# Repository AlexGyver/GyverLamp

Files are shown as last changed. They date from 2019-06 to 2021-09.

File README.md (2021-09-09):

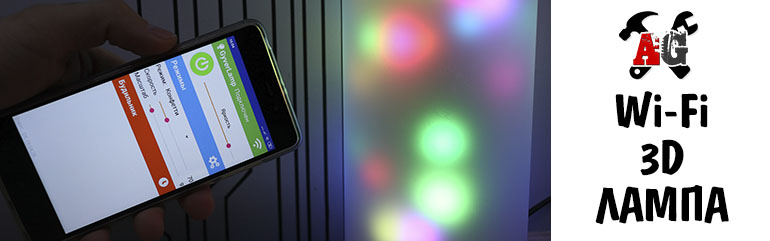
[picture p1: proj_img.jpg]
PROJECT_PHOTO

# Крутая WiFi лампа на esp8266 своими руками
* [Описание проекта](#chapter-0)
* [Папки проекта](#chapter-1)
* [Схемы подключения](#chapter-2)
* [Материалы и компоненты](#chapter-3)
* [Как скачать и прошить](#chapter-4)
* [FAQ](#chapter-5)
* [Полезная информация](#chapter-6)
AlexGyver YouTube (https://www.youtube.com/channel/UCgtAOyEQdAyjvm9ATCi_Aig?sub_confirmation=1)

## Описание проекта
Представляю вашему вниманию светильник на адресных светодиодах с кучей эффектов, управлением по Wi-Fi и функцией будильник-рассвет!
### Железо
- Проект собран на базе микроконтроллера ESP8266 в лице платы NodeMCU или Wemos D1 mini (неважно, какую из этих плат использовать!).
- Вместо адресной ленты используется гибкая адресная матрица 16×16, что выходит дешевле ленты (матрица 16×16 стоит 1500р, она состоит из 256 диодов с плотностью 100 штук на метр. Лента такой же плотности стоит 1000р за метр (за 100 светодиодов). Для склейки матрицы размером 16×16 понадобится 2.5 метра ленты, то есть 2500р. А готовая матрица стоит на 1000р дешевле!).
- Система управляется со смартфона по Wi-Fi (приложение GyverLamp для Android), а также “оффлайн” с кнопки на корпусе (сенсорная кнопка на TTP223).

### Фишки
- 14 крутых эффектов
- Настройка скорости, яркости и “масштаба” для каждого эффекта
- Настройка эффектов со смартфона
- Работа системы как в локальной сети, так и в режиме “точки доступа”
- Встроенный Wi-Fi менеджер для удобной настройки сети
- Система получает точное время из Интернета
- Управление кнопкой: смена режима, настройка яркости, вкл/выкл
- Режим будильник-рассвет: менеджер будильников на неделю в приложении

### Корпус
- Корпус выглядит очень презентабельно, несмотря на простоту и доступность материалов
- Рассеиватель – матовый плафон из Леруа Мерлен
- Остальные элементы корпуса – канализационные трубы, в лучших традициях жанра!
- Страница проекта на сайте: https://alexgyver.ru/GyverLamp/

## Папки
**ВНИМАНИЕ! Если это твой первый опыт работы с Arduino, читай [инструкцию](#chapter-4)**
- **libraries** - библиотеки проекта. Заменить имеющиеся версии
- **firmware** - прошивки для Arduino
- **schemes** - схемы подключения компонентов

## Схемы
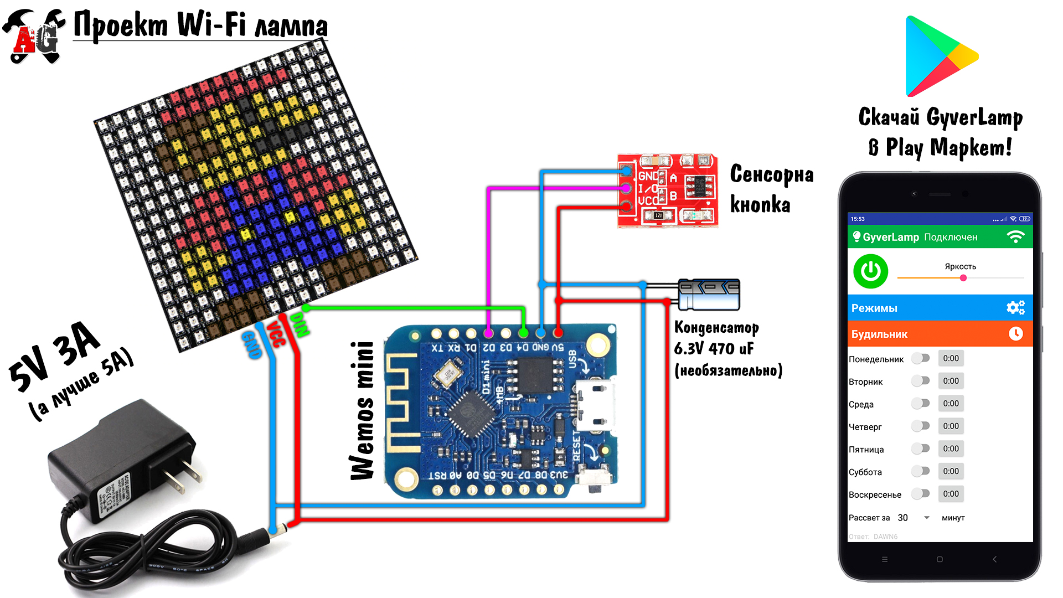
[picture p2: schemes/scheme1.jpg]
SCHEME

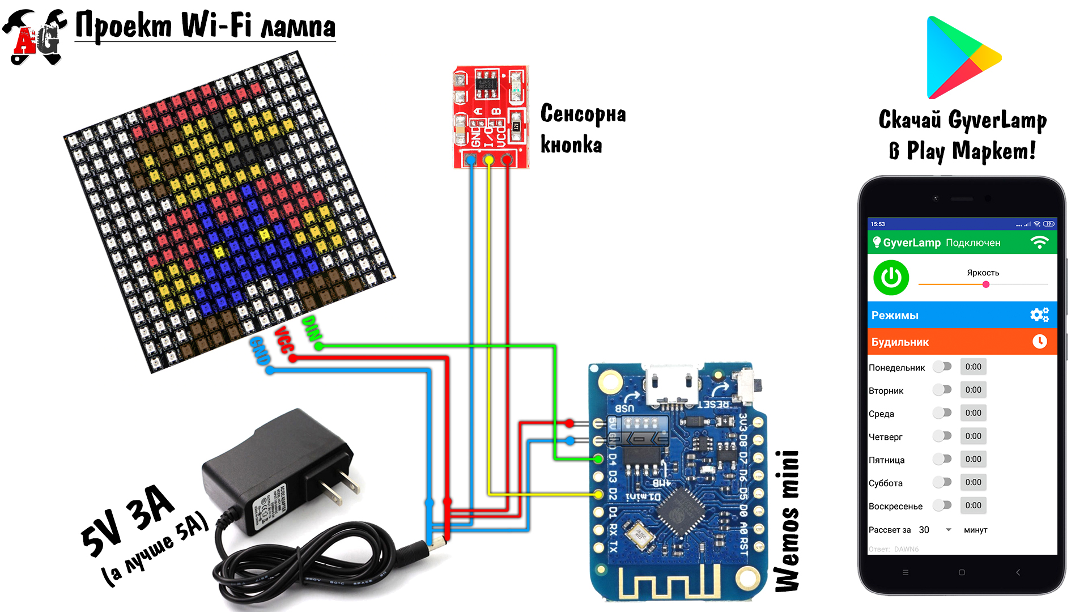
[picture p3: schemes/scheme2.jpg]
SCHEME


## Материалы и компоненты
### Ссылки оставлены на магазины, с которых я закупаюсь уже не один год
Wemos D1 mini – искать
* https://ali.ski/1_oipS
* https://ali.ski/EO_w2z
* https://ali.ski/QKymk
* https://ali.ski/Pzxf_G
NodeMCU – искать
* https://ali.ski/F2FeBB
* https://ali.ski/j76J_I
Матрица 16×16 – искать
* https://ali.ski/lkB8g
* https://ali.ski/CaiZgG
* https://ali.ski/9hcHX
* https://ali.ski/4zxlz
* Матрица 8×8 купить в РФ
Адресная лента (для DIY матрицы)
* https://ali.ski/oEXGJI
* https://ali.ski/VuxYof
* Купить в РФ, 60 свет/метр, 30 свет/метр
* Black PCB / White PCB – цвет подложки ленты, чёрная / белая. В видео была чёрная
* 1m/5m – длина ленты в метрах (чтобы заказать 2 метра, берите два заказа 1m, очевидно)
* 30/60/74/96/100/144 – количество светодиодов на 1 метр ленты. В видео использовалась лента 60 диодов на метр
* IP30 лента без влагозащиты (как на видео)
* IP65 лента покрыта силиконом
* IP67 лента полностью в силиконовом коробе
* Постфикс ECO – лента чуть более низкого качества, меньше меди, на длинной ленте будет сильно проседать яркость
Сенсорная кнопка – искать
* https://ali.ski/zzTzeO
* https://ali.ski/DbCM-A
* БП 5V искать (минимум 3A на каждые 100 LED)
* https://ali.ski/8dQhKV
* https://ali.ski/-ppLAQ
* Мощные https://ali.ski/UwKWR
* Мощные https://ali.ski/W-3Gs
* БП 60W (купить в РФ)
* БП 100W (купить в РФ)
Проводочки – искать
* https://ali.ski/Jb-RZJ
Сантех
* Труба D50 длина 250
* Труба D40 короткая
* Заглушка D40

## Вам скорее всего пригодится
* [Всё для пайки (паяльники и примочки)](http://alexgyver.ru/all-for-soldering/)
* [Недорогие инструменты](http://alexgyver.ru/my_instruments/)
* [Все существующие модули и сенсоры Arduino](http://alexgyver.ru/arduino_shop/)
* [Электронные компоненты](http://alexgyver.ru/electronics/)
* [Аккумуляторы и зарядные модули](http://alexgyver.ru/18650/)

## Как скачать и прошить
* [Первые шаги с Arduino](http://alexgyver.ru/arduino-first/) - ультра подробная статья по началу работы с Ардуино, ознакомиться первым делом!
* Скачать архив с проектом
> На главной странице проекта (где ты читаешь этот текст) вверху справа зелёная кнопка **Clone or download**, вот её жми, там будет **Download ZIP**
* Установить библиотеки в  
`C:\Program Files (x86)\Arduino\libraries\` (Windows x64)  
`C:\Program Files\Arduino\libraries\` (Windows x86)
* **Подключить внешнее питание 5 Вольт**
* Подключить плату к компьютеру
* Файл/Настройки, вставить ссылку http://arduino.esp8266.com/stable/package_esp8266com_index.json в в текст-бокс для дополнительных ссылок для менеджера плат
* Открыть Инструменты/Плата/Менеджер плат…, найти esp8266 by ESP8266 Community, установить версию 2.5.0
* Открыть Инструменты, настроить Плату, Порт и другие параметры как на скриншоте
* Загрузить прошивку

## Настройки в коде
    // -------- ВРЕМЯ -------
    GMT 3              // смещение (москва 3)
    NTP_ADDRESS  "europe.pool.ntp.org"    // сервер времени

    // -------- РАССВЕТ -------
    DAWN_BRIGHT 200       // макс. яркость рассвета
    DAWN_TIMEOUT 1        // сколько рассвет светит после времени будильника, минут

    // ---------- МАТРИЦА ---------
    BRIGHTNESS 40         // стандартная маскимальная яркость (0-255)
    CURRENT_LIMIT 2000    // лимит по току в миллиамперах, автоматически управляет яркостью (пожалей свой блок питания!) 0 - выключить лимит

    WIDTH 16              // ширина матрицы
    HEIGHT 16             // высота матрицы

    COLOR_ORDER GRB       // порядок цветов на ленте. Если цвет отображается некорректно - меняйте. Начать можно с RGB

    MATRIX_TYPE 0         // тип матрицы: 0 - зигзаг, 1 - параллельная
    CONNECTION_ANGLE 0    // угол подключения: 0 - левый нижний, 1 - левый верхний, 2 - правый верхний, 3 - правый нижний
    STRIP_DIRECTION 0     // направление ленты из угла: 0 - вправо, 1 - вверх, 2 - влево, 3 - вниз
    // при неправильной настрйоке матрицы вы получите предупреждение "Wrong matrix parameters! Set to default"
    // шпаргалка по настройке матрицы здесь! https://alexgyver.ru/matrix_guide/

    // --------- ESP --------
    ESP_MODE 1
    // 0 - точка доступа (192.168.4.1 или другой)
    // 1 - локальный (192.168.1.232 или другой)

    // -------- Менеджер WiFi ---------
    AC_SSID "AutoConnectAP"
    AC_PASS "12345678"

    // -------------- AP ---------------
    AP_SSID "GyverLamp"
    AP_PASS "12345678"
    AP_PORT 8888

## FAQ
### Основные вопросы
В: Как скачать с этого грёбаного сайта?  
О: На главной странице проекта (где ты читаешь этот текст) вверху справа зелёная кнопка **Clone or download**, вот её жми, там будет **Download ZIP**

В: Скачался какой то файл .zip, куда его теперь?  
О: Это архив. Можно открыть стандартными средствами Windows, но думаю у всех на компьютере установлен WinRAR, архив нужно правой кнопкой и извлечь.

В: Я совсем новичок! Что мне делать с Ардуиной, где взять все программы?  
О: Читай и смотри видос http://alexgyver.ru/arduino-first/

В: Вылетает ошибка загрузки / компиляции!
О: Читай тут: https://alexgyver.ru/arduino-first/#step-5

В: Сколько стоит?  
О: Ничего не продаю.

### Вопросы по этому проекту

## Полезная информация
* [Мой сайт](http://alexgyver.ru/)
* [Основной YouTube канал](https://www.youtube.com/channel/UCgtAOyEQdAyjvm9ATCi_Aig?sub_confirmation=1)
* [YouTube канал про Arduino](https://www.youtube.com/channel/UC4axiS76D784-ofoTdo5zOA?sub_confirmation=1)
* [Мои видеоуроки по пайке](https://www.youtube.com/playlist?list=PLOT_HeyBraBuMIwfSYu7kCKXxQGsUKcqR)
* [Мои видеоуроки по Arduino](http://alexgyver.ru/arduino_lessons/)

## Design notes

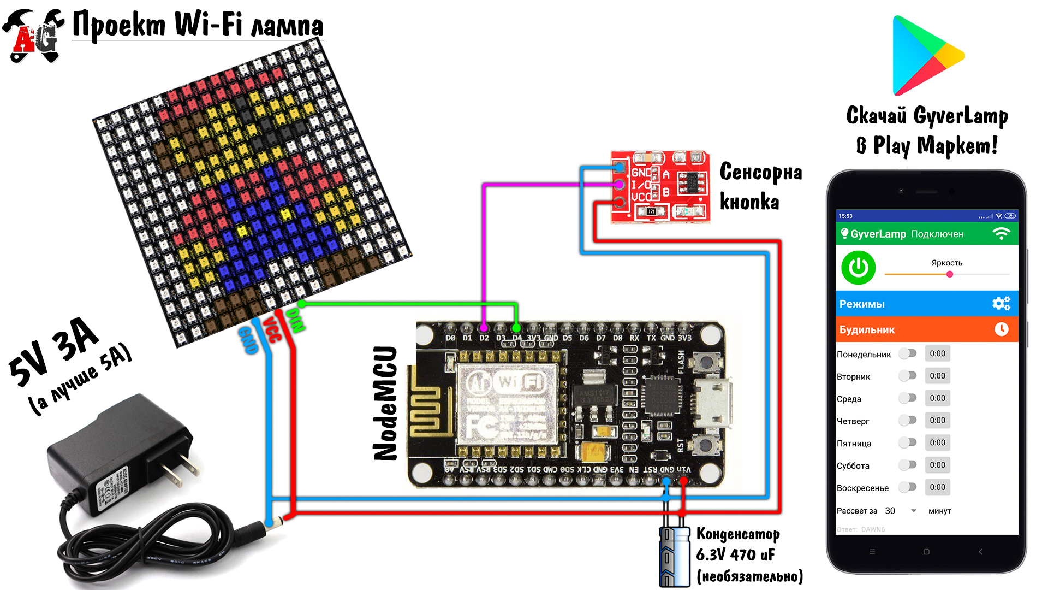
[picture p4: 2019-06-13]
schemes/scheme0.jpg

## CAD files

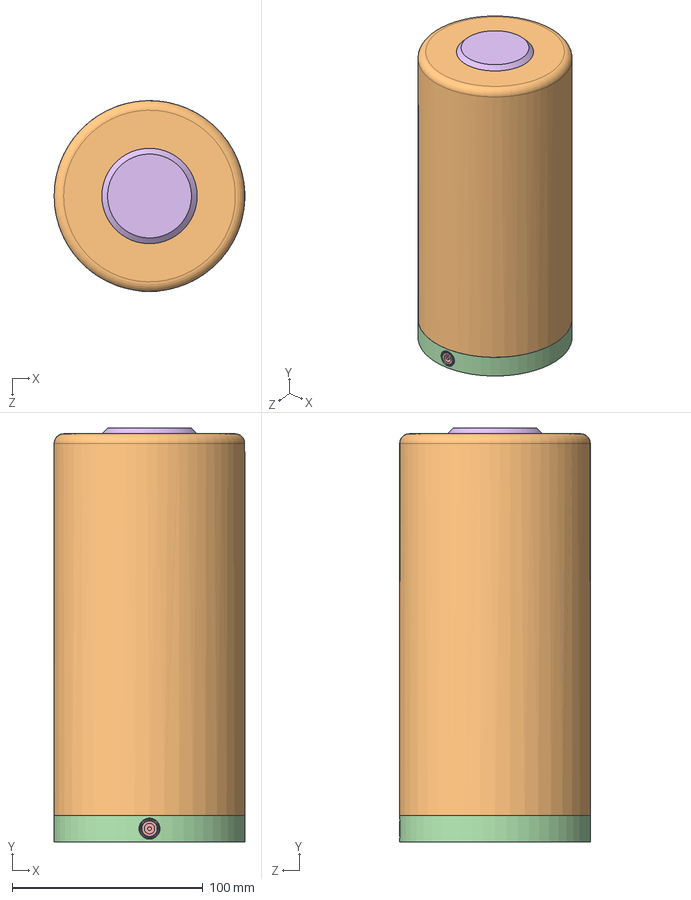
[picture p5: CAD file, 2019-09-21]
3D_print/kokos/исходник/GyverLamp.SLDASM
100.0 x 217.0 x 100.0 mm
Основание
Плафон 20х10
LED_strip 12 x 15
постамент
dc_power_jack_3p5x1p35mm
крышка
Lolin NodeMCU ESP8266 V3
TTP

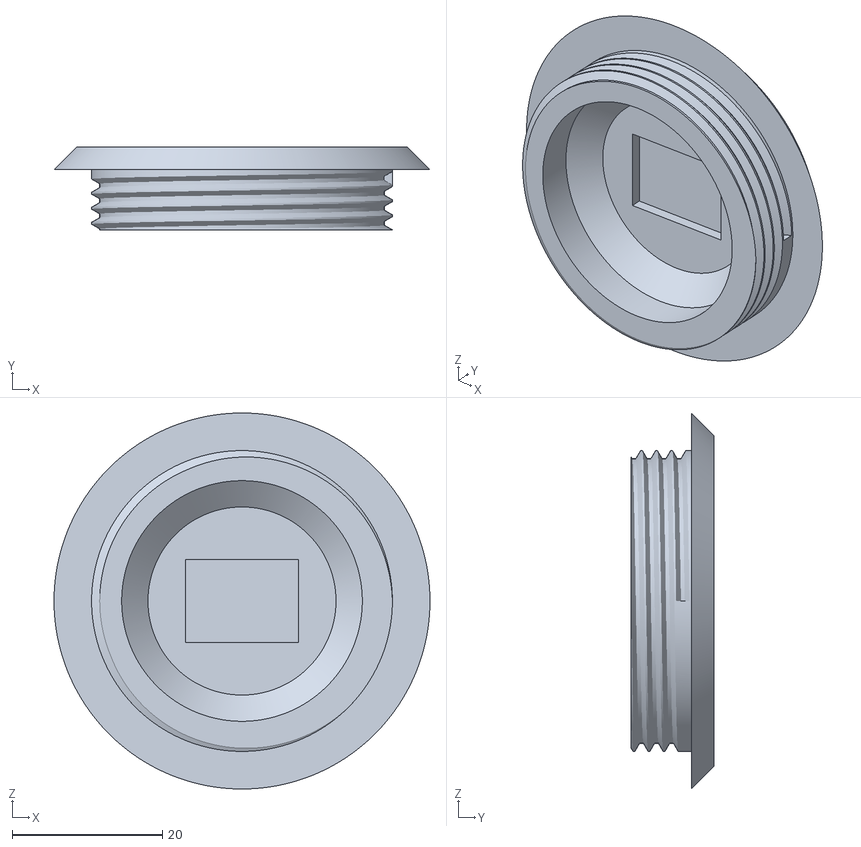
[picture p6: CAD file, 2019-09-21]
3D_print/kokos/stl/крышка.STL
50.0 x 11.0 x 50.0

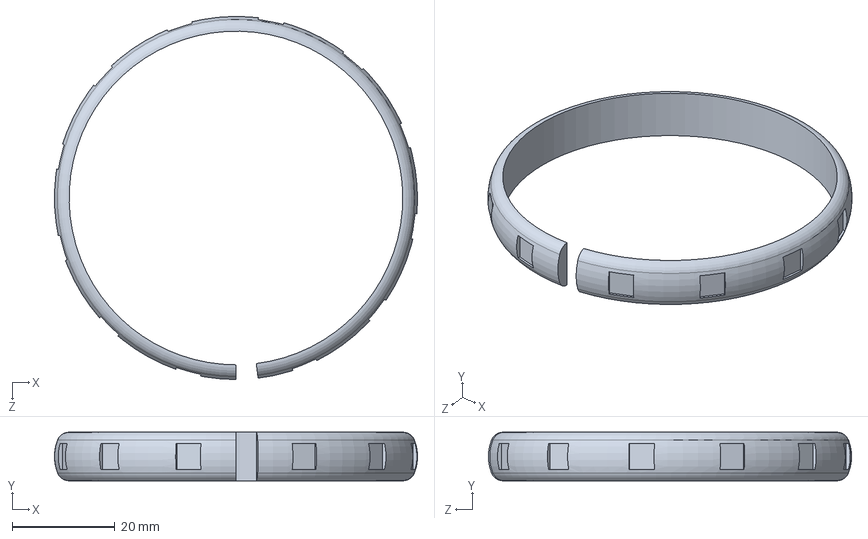
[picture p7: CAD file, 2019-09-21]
3D_print/kokos/исходник/LED_strip 12.SLDPRT
70.7 x 9.50 x 70.7 mm

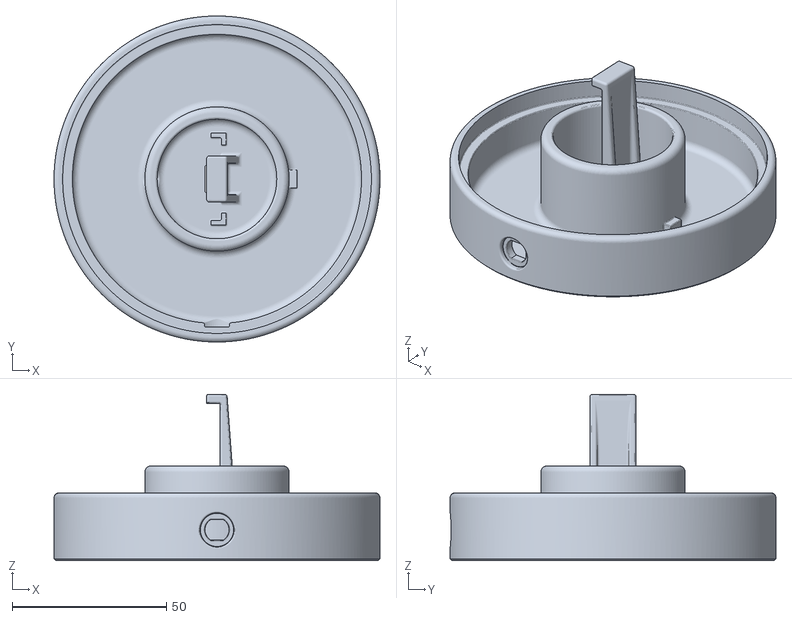
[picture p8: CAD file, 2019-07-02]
3D_print/Евгений/STL/Lamp_Down_DC-output.stl
105.8 x 105.8 x 54.0

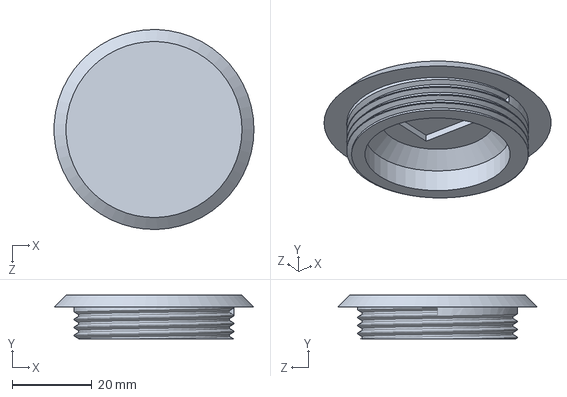
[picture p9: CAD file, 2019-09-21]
3D_print/kokos/исходник/крышка.SLDPRT
50.0 x 11.0 x 50.0 mm

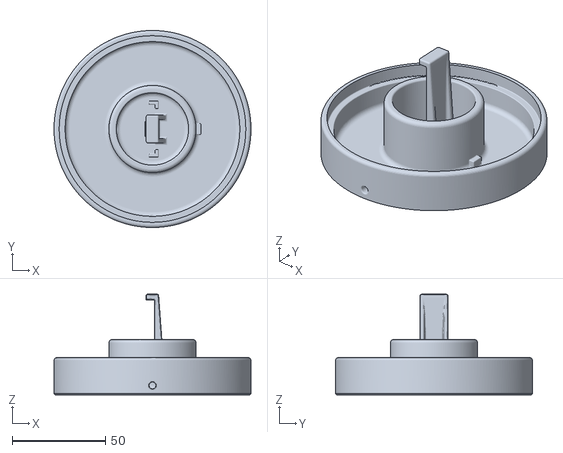
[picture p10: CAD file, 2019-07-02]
3D_print/Евгений/STL/Lamp_Down.stl
105.8 x 105.8 x 54.0

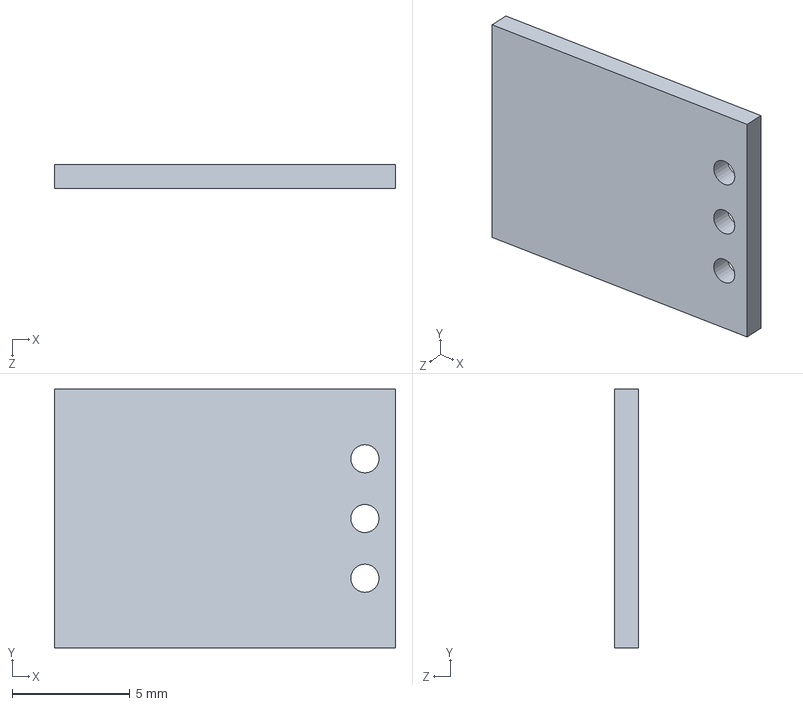
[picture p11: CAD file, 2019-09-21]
3D_print/kokos/исходник/TTP.SLDPRT
14.5 x 11.0 x 1.00 mm

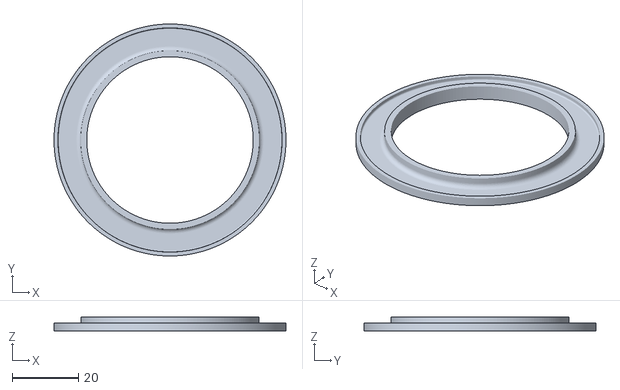
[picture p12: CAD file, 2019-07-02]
3D_print/Евгений/STL/ring_for_paper.stl
70.0 x 70.0 x 4.20

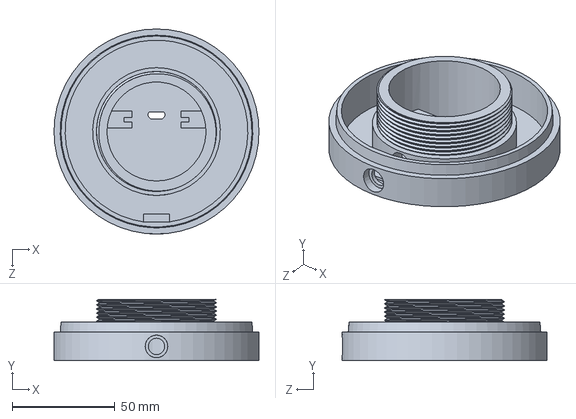
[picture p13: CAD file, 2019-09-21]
3D_print/kokos/исходник/постамент.SLDPRT
100.0 x 30.0 x 100.0 mm

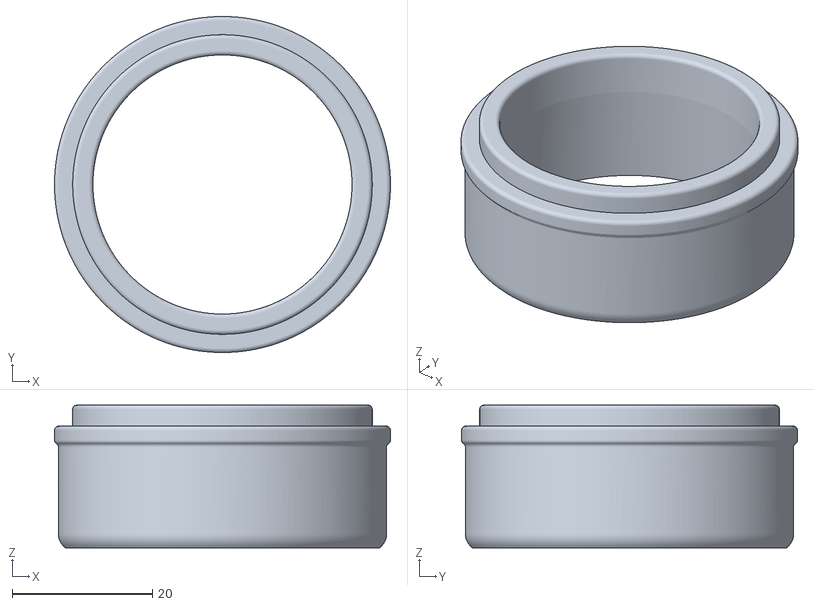
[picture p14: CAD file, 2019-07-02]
3D_print/Евгений/STL/Ring_top.stl
48.0 x 48.0 x 20.4

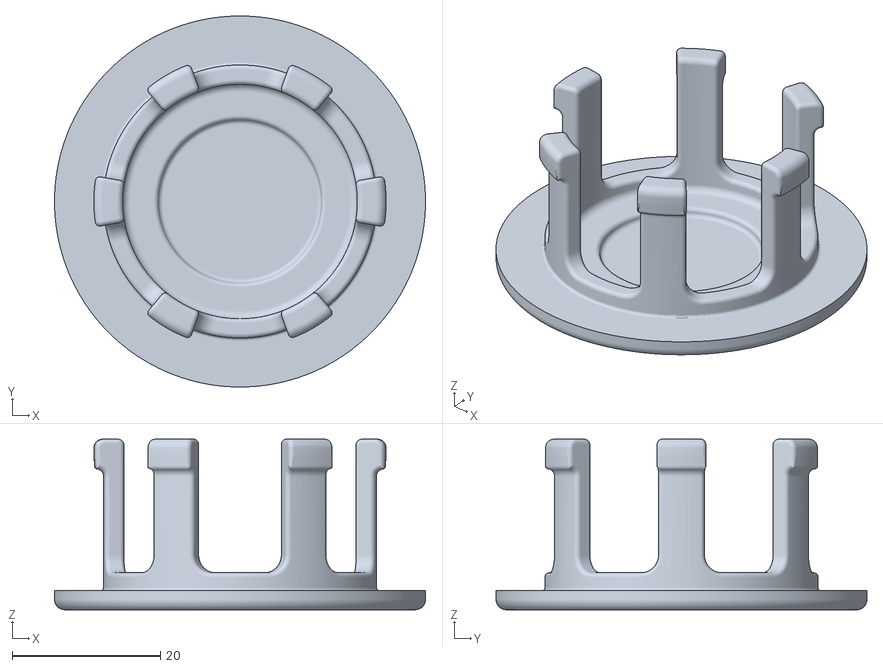
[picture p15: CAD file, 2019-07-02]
3D_print/Евгений/STL/Lamp-Top.stl
50.0 x 50.0 x 23.0

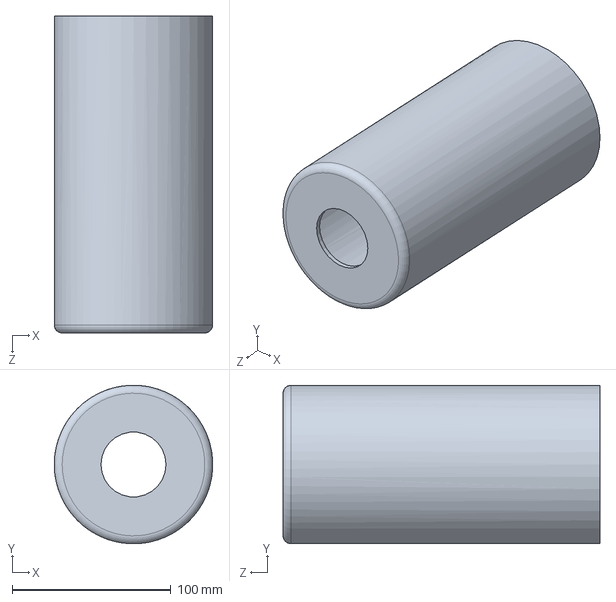
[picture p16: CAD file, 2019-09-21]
3D_print/kokos/исходник/Плафон 20х10.SLDPRT
100.0 x 100.0 x 200.0 mm

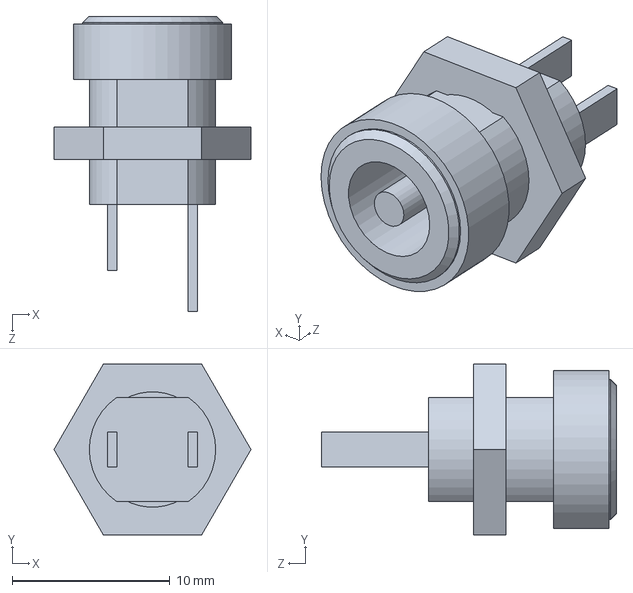
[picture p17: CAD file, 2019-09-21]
3D_print/kokos/исходник/dc_power_jack_3p5x1p35mm.SLDPRT
12.5 x 10.8 x 18.7 mm

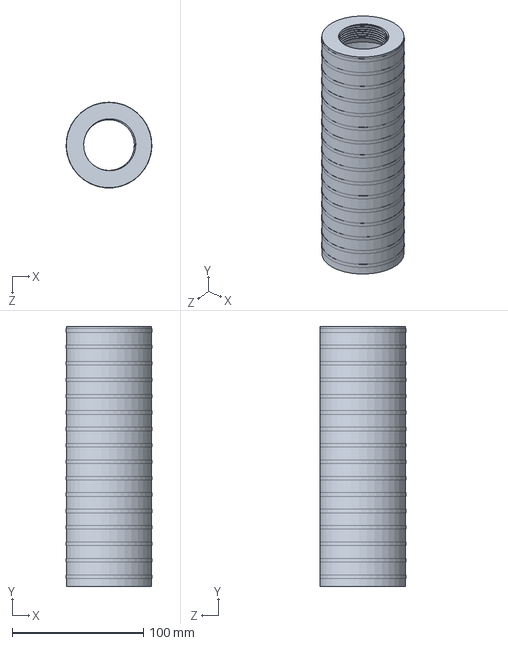
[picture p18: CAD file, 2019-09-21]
3D_print/kokos/исходник/Основание.SLDPRT
65.3 x 198.0 x 65.3 mm

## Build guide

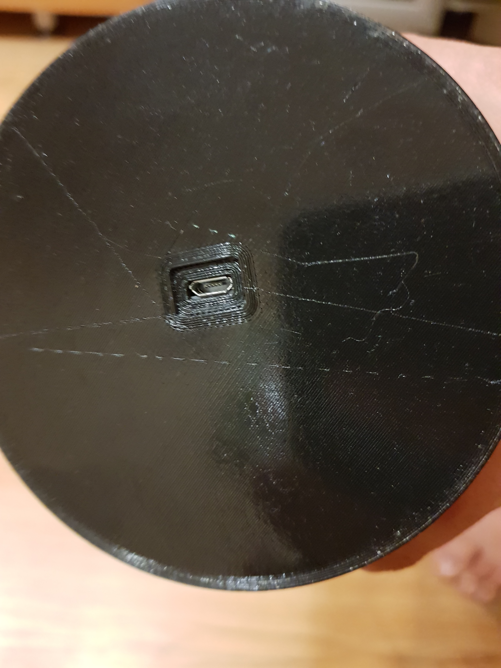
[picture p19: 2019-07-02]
3D_print/Евгений/photo (5).jpg

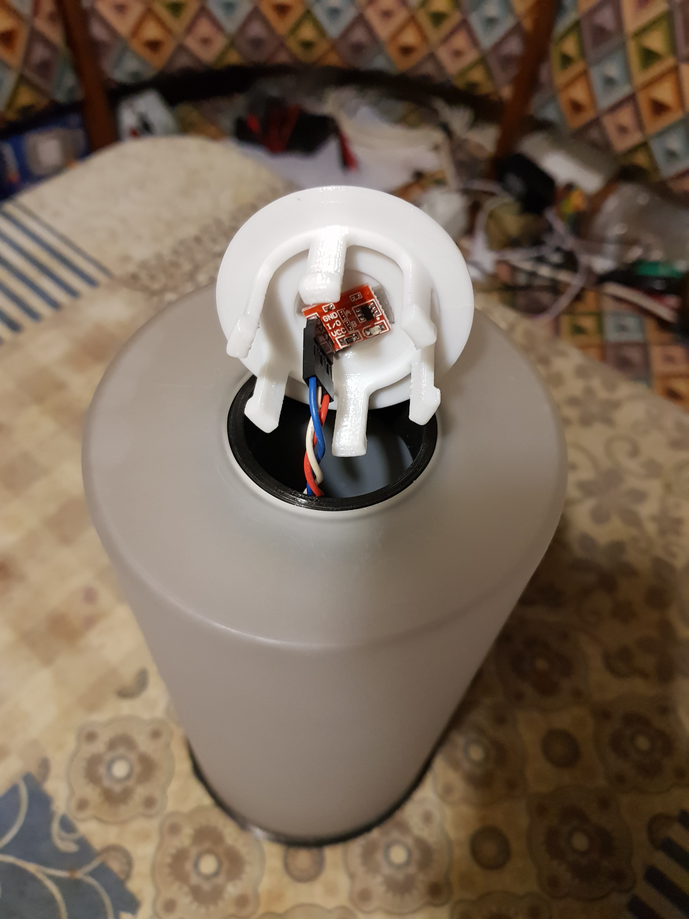
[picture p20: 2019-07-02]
3D_print/Евгений/photo (1).jpg

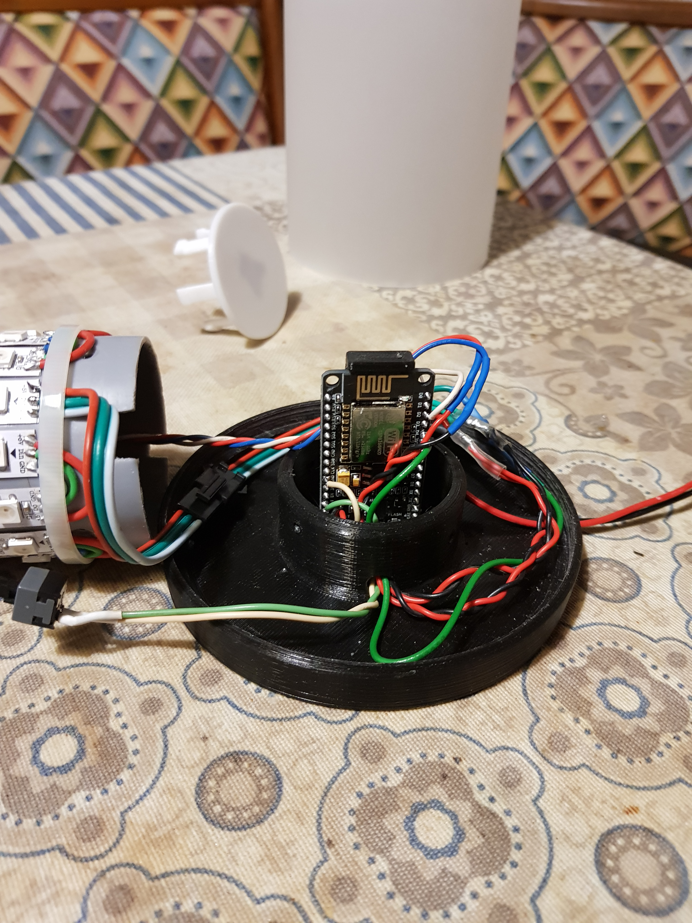
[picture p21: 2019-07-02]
3D_print/Евгений/photo (3).jpg

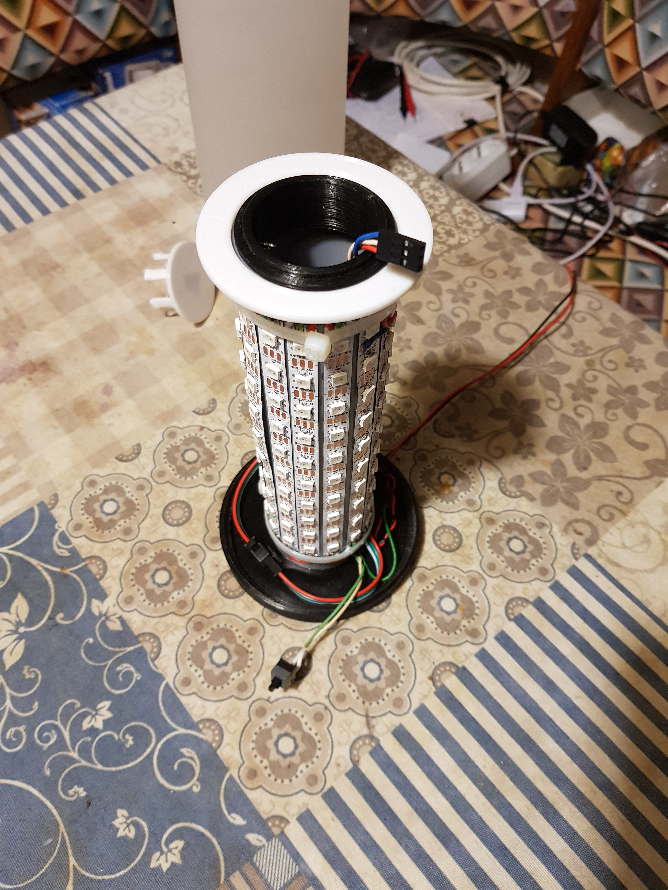
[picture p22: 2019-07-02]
3D_print/Евгений/photo (2).jpg

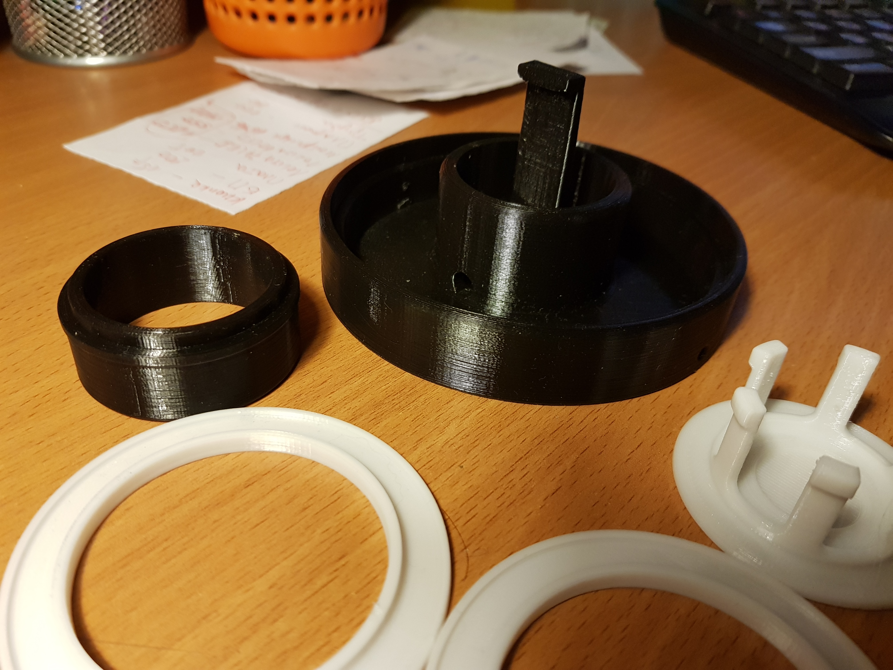
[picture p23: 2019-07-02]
3D_print/Евгений/photo (4).jpg

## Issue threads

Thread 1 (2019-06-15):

Настройки яркости

Yusupoff, 2019-06-15:
При установке яркость на минимальную она постепенно увеличивается обратно до максимума

AlexGyver, 2019-07-01:
проверь как себя чувствует кнопка, "отпускается" ли она

vvip-68, 2019-07-03:
Кнопки вообще нет. Только матрица. И да - если в программе выставить яркость на минимум, она постепенно сама увеличивается до максимума. Правда, я это пробовал в версии 1.2; Не знаю что там с этим в 1.3 или 1.4

AlexGyver, 2019-07-03:
Вот отсутствие кнопки не означает того, что микроконтроллер об этом в курсе. Пин кнопки ловит наводки из воздуха и интерпретирует их в случайное значение17:41, 3 июля 2019 г., "vvip-68" <notifications@github.com>:Кнопки вообще нет. Только матрица. И да - если в программе выставить яркость на минимум, она постепенно сама увеличивается до максимума. Правда, я это пробовал в версии 1.2; Не знаю что там с этим в 1.3 или 1.4

—You are receiving this because you commented.Reply to this email directly, view it on GitHub, or mute the thread.
Яндекс.Почта

Denischet, 2021-10-01:
> Кнопки вообще нет. Только матрица. И да - если в программе выставить яркость на минимум, она постепенно сама увеличивается до максимума. Правда, я это пробовал в версии 1.2; Не знаю что там с этим в 1.3 или 1.4

Не уверен, что увижу ответ, но все же спрошу. Решил ли проблему? Если да  то как? У меня яркость или растет до максимума или падает до минимума. Кнопка есть, но не залипшая, не моргает диодом, во всяком случае. Буду признателен за обратную связь.

vvip-68, 2021-10-01:
*  Этот проект давно устаревший и уже не поддерживается. Все функциональные возможности этого проекта перенесены в GyverPanelWiFi и добавлено много чего еще. Несмотря на то, что проект называется  Panel — по сути это всё та же лампа.
 
*  Описанное происходит скорее всего из за неправильного указания (а следовательно и инициализации) типа кнопки в скетче. Например — подключена сенсорная кнопка, а в скетче кнопка указана как обычная тактовая или наоборот.
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
Не уверен, что увижу ответ, но все же спрошу. Решил ли проблему? Если да то как? У меня яркость или растет до максимума или падает до минимума. Кнопка есть, но не залипшая, не моргает диодом, во всяком случае. Буду признателен за обратную связь.
—
You are receiving this because you commented.
Reply to this email directly,  view it on GitHub , or  unsubscribe .
Triage notifications on the go with GitHub Mobile for  iOS or  Android .   
 
С уважением,
Вадим Пузанов
 

Yusupoff, 2021-10-04:
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

В последних версиях не наблюдается

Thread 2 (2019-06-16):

Отображение времени (часы)

dipcore, 2019-06-16:
Круто бы добавить режим отображения времени. На такая крутой адресной матрице это должно выглядеть хорошо. Можно также сделатьнесколько эфектов отображения/анимации времени.

vvip-68, 2019-06-17:
> Круто бы добавить режим отображения времени. На такой крутой адресной матрице это должно выглядеть хорошо. Можно также сделать несколько эффектов отображения/анимации времени.
Вы конструкцию лампы то видели? При внутреннем радиусе матрицы 50 мм и внешнем радиусе плафона 100 мм цифр будет не различить совсем. А для часов - есть другой проект. Именно в виде плоской матрицы. С эффектом и часами.

dipcore, 2019-06-17:
> Вы конструкцию лампы то видели? При внутреннем диаметре матрицы 50 мм и внешнем диаметре плафона 100 мм цифр будет не различить совсем. А для часов - есть другой проект. Именно в виде плоской матрицы. С эффектом и часами.

Я бы небыл так катигоричен. Конструкцию я видел и отображение времени вполне реализуемо.

vvip-68, 2019-06-17:
Вполне реализуемо. Только зачем? На лампе времени видно не будет, а для проекта плоской матрицы - время есть. Вот время на внешнем индикаторе типа TM1637 - актуально.

dipcore, 2019-06-22:
Будет хорошо видно большие цифры даже через рассеиватель. А со скроллингом было бы вообще класс.

vvip-68, 2019-07-03:
Ну так ставьте GyverMatrixBT или GyverMatrixWiFi в плафон и будет вам счастье.

Pats1337, 2022-06-05:
Тестировал отображение времени на лампе, довольно плохо читаются цифры из-за рассеивающей поверхности плафона из Леруа.

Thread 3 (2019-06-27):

проблема с таймингом без интернета

baxster, 2019-06-27:
При отсутствии интернета вызов метода `timeClient.update();` вешает обработку тика эффекта на секунду. В итоге нет реакции на изменение скорости и т.п.

В библиотечном методе `NTPClient::forceUpdate()` есть кусок кода:
`  // Wait till data is there or timeout...
  byte timeout = 0;
  int cb = 0;
  do {
    delay ( 10 );
    cb = this->_udp->parsePacket();
    if (timeout > 100) return false; // timeout after 1000 ms
    timeout++;
  } while (cb == 0);`

В итоге при каждом выполнении цикла эффекта мы попадаем на таймаут, а так как используется `delay`, а не `millis`, то мы попадаем с эффектами лампы.
Надо как-то это учесть в работе самой лампы и возможно стоит как-то переписать это на `millis()`

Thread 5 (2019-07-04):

добавил некоторве функции и упростил настройку статического IP

Yusupoff, 2019-07-04:
`/*
  Скетч к проекту "Многофункциональный RGB светильник"
  Страница проекта (схемы, описания): https://alexgyver.ru/GyverLamp/
  Исходники на GitHub: https://github.com/AlexGyver/GyverLamp/
  Нравится, как написан код? Поддержи автора! https://alexgyver.ru/support_alex/
  Автор: AlexGyver, AlexGyver Technologies, 2019
  https://AlexGyver.ru/
*/

/*
  Версия 1.2:
  - Добавлена настройка статического IP
  - Добавлен эффект "Цвет"
  - Добавлен эффект "Снег"
  - Добавлен эффект "Матрица"
  - Добавлен эффект "Светлячки"
*/

// Ссылка для менеджера плат:
// http://arduino.esp8266.com/stable/package_esp8266com_index.json

// ============= НАСТРОЙКИ =============
// -------- ВРЕМЯ -------
#define GMT 3              // смещение (москва 3)
#define NTP_ADDRESS  "europe.pool.ntp.org"    // сервер времени

// -------- РАССВЕТ -------
#define DAWN_BRIGHT 200       // макс. яркость рассвета
#define DAWN_TIMEOUT 1        // сколько рассвет светит после времени будильника, минут

// ---------- МАТРИЦА ---------
#define BRIGHTNESS 40         // стандартная маскимальная яркость (0-255)
#define CURRENT_LIMIT 2000    // лимит по току в миллиамперах, автоматически управляет яркостью (пожалей свой блок питания!) 0 - выключить лимит

#define WIDTH 6              // ширина матрицы
#define HEIGHT 9             // высота матрицы

#define COLOR_ORDER GRB       // порядок цветов на ленте. Если цвет отображается некорректно - меняйте. Начать можно с RGB

#define MATRIX_TYPE 1         // тип матрицы: 0 - зигзаг, 1 - параллельная
#define CONNECTION_ANGLE 2    // угол подключения: 0 - левый нижний, 1 - левый верхний, 2 - правый верхний, 3 - правый нижний
#define STRIP_DIRECTION 3     // направление ленты из угла: 0 - вправо, 1 - вверх, 2 - влево, 3 - вниз
// при неправильной настройке матрицы вы получите предупреждение "Wrong matrix parameters! Set to default"
// шпаргалка по настройке матрицы здесь! https://alexgyver.ru/matrix_guide/

// --------- ESP --------
const char HOSTNAME[] = "GyverLamp";
#define ESP_MODE 1
// 0 - точка доступа
// 1 - локальный
byte IP_AP[] = {192, 168, 4, 1};   // статический IP точки доступа (менять только последнюю цифру)

//#define WIFIMGR_PORTAL_TIMEOUT 1
//#define WIFIMGR_SET_MANUAL_IP
#ifdef WIFIMGR_SET_MANUAL_IP
  char static_ip[16] = "10.0.1.56";
  char static_gw[16] = "10.0.1.1";
  char static_sn[16] = "255.255.255.0";
#endif

// ----- AP (точка доступа) -------
#define AP_SSID "GyverLamp"
#define AP_PASS "12345678"
#define AP_PORT 8888

// -------- Менеджер WiFi ---------
#define AC_SSID "AutoAP"
#define AC_PASS "12345678"

// ============= ДЛЯ РАЗРАБОТЧИКОВ =============
#define LED_PIN 2             // пин ленты
#define BTN_PIN 3
#define MODE_AMOUNT 18

#define NUM_LEDS WIDTH * HEIGHT
#define SEGMENTS 1            // диодов в одном "пикселе" (для создания матрицы из кусков ленты)
// ---------------- БИБЛИОТЕКИ -----------------
#define FASTLED_INTERRUPT_RETRY_COUNT 0
#define FASTLED_ALLOW_INTERRUPTS 0
#define FASTLED_ESP8266_RAW_PIN_ORDER
#define NTP_INTERVAL 60 * 1000    // обновление (1 минута)

#include "timerMinim.h"
#include <FastLED.h>
#include <ESP8266WiFi.h>
#include <DNSServer.h>
#include <ESP8266WebServer.h>
#include <WiFiManager.h>
#include <WiFiUdp.h>
#include <EEPROM.h>
#include <NTPClient.h>
#include <GyverButton.h>

// ------------------- ТИПЫ --------------------
CRGB leds[NUM_LEDS];
WiFiServer server(88);
WiFiUDP Udp;
WiFiUDP ntpUDP;
NTPClient timeClient(ntpUDP, NTP_ADDRESS, GMT * 3600, NTP_INTERVAL);
timerMinim timeTimer(3000);
GButton touch(BTN_PIN, LOW_PULL, NORM_OPEN);

// ----------------- ПЕРЕМЕННЫЕ ------------------
const char AP_NameChar[] = AP_SSID;
const char WiFiPassword[] = AP_PASS;
unsigned int localPort = AP_PORT;
char packetBuffer[UDP_TX_PACKET_MAX_SIZE + 1]; //buffer to hold incoming packet
String inputBuffer;
static const byte maxDim = max(WIDTH, HEIGHT);
struct {
  byte brightness = 50;
  byte speed = 30;
  byte scale = 40;
} modes[MODE_AMOUNT];

struct {
  boolean state = false;
  int time = 0;
} alarm[7];

byte dawnOffsets[] = {5, 10, 15, 20, 25, 30, 40, 50, 60};
byte dawnMode;
boolean dawnFlag = false;
long thisTime;
boolean manualOff = false;

int8_t currentMode = 0;
boolean loadingFlag = true;
boolean ONflag = true;
uint32_t eepromTimer;
boolean settChanged = false;
// Конфетти, Огонь, Радуга верт., Радуга гориз., Смена цвета,
// Безумие 3D, Облака 3D, Лава 3D, Плазма 3D, Радуга 3D,
// Павлин 3D, Зебра 3D, Лес 3D, Океан 3D,

unsigned char matrixValue[8][16];

void setup() {
  //ESP.wdtDisable();
  //ESP.wdtEnable(WDTO_8S);
  wifi_station_set_hostname(const_cast<char*>(HOSTNAME));
  // ЛЕНТА
  FastLED.addLeds<WS2812B, LED_PIN, COLOR_ORDER>(leds, NUM_LEDS)/*.setCorrection( TypicalLEDStrip )*/;
  FastLED.setBrightness(BRIGHTNESS);
  if (CURRENT_LIMIT > 0) FastLED.setMaxPowerInVoltsAndMilliamps(5, CURRENT_LIMIT);
  FastLED.clear();
  FastLED.show();

  touch.setStepTimeout(100);
  touch.setClickTimeout(500);

  Serial.begin(115200);
  Serial.println();

  // WI-FI
  if (ESP_MODE == 0) {    // режим точки доступа
    WiFi.softAP(AP_NameChar, WiFiPassword);
    IPAddress myIP = WiFi.softAPIP();
    Serial.print("Access point Mode");
    Serial.print("AP IP address: ");
    Serial.println(myIP);
    server.begin();
  } else {                // подключаемся к роутеру
    Serial.print("WiFi manager");
    WiFiManager wifiManager;

    #ifdef WIFIMGR_SET_MANUAL_IP
      IPAddress _ip,_gw,_sn;
      _ip.fromString(static_ip);
      _gw.fromString(static_gw);
      _sn.fromString(static_sn);
      wifiManager.setSTAStaticIPConfig(_ip, _gw, _sn);
    #endif
    #ifdef WIFIMGR_PORTAL_TIMEOUT
    wifiManager.setConfigPortalTimeout(WIFIMGR_PORTAL_TIMEOUT);
    #endif
    wifiManager.autoConnect(HOSTNAME);
    wifiManager.setDebugOutput(false);
    //wifiManager.resetSettings();

    Serial.print("Connected! IP address: ");
    Serial.println("local ip");
    Serial.println(WiFi.localIP());
    Serial.println(WiFi.gatewayIP());
    Serial.println(WiFi.subnetMask());
    server.begin();
  }

  Serial.printf("UDP server on port %d\n", localPort);
  Udp.begin(localPort);

  // EEPROM
  EEPROM.begin(202);
  delay(50);
  if (EEPROM.read(198) != 20) {   // первый запуск
    EEPROM.write(198, 20);
    EEPROM.commit();

    for (byte i = 0; i < MODE_AMOUNT; i++) {
      EEPROM.put(3 * i + 40, modes[i]);
      EEPROM.commit();
    }
    for (byte i = 0; i < 7; i++) {
      EEPROM.write(5 * i, alarm[i].state);   // рассвет
      eeWriteInt(5 * i + 1, alarm[i].time);
      EEPROM.commit();
    }
    EEPROM.write(199, 0);   // рассвет
    EEPROM.write(200, 0);   // режим
    EEPROM.commit();
  }
  for (byte i = 0; i < MODE_AMOUNT; i++) {
    EEPROM.get(3 * i + 40, modes[i]);
  }
  for (byte i = 0; i < 7; i++) {
    alarm[i].state = EEPROM.read(5 * i);
    alarm[i].time = eeGetInt(5 * i + 1);
  }
  dawnMode = EEPROM.read(199);
  currentMode = (int8_t)EEPROM.read(200);

  // отправляем настройки
  sendCurrent();
  char reply[inputBuffer.length() + 1];
  inputBuffer.toCharArray(reply, inputBuffer.length() + 1);
  Udp.beginPacket(Udp.remoteIP(), Udp.remotePort());
  Udp.write(reply);
  Udp.endPacket();

  timeClient.begin();
  memset(matrixValue, 0, sizeof(matrixValue));

  randomSeed(micros());
}

void loop() {
  parseUDP();

  effectsTick();
  eepromTick();
  timeTick();
  buttonTick();
  //ESP.wdtFeed();   // пнуть собаку
  yield();
}

void eeWriteInt(int pos, int val) {
  byte* p = (byte*) &val;
  EEPROM.write(pos, *p);
  EEPROM.write(pos + 1, *(p + 1));
  EEPROM.write(pos + 2, *(p + 2));
  EEPROM.write(pos + 3, *(p + 3));
  EEPROM.commit();
}

int eeGetInt(int pos) {
  int val;
  byte* p = (byte*) &val;
  *p        = EEPROM.read(pos);
  *(p + 1)  = EEPROM.read(pos + 1);
  *(p + 2)  = EEPROM.read(pos + 2);
  *(p + 3)  = EEPROM.read(pos + 3);
  return val;
}
`

vitaliy172, 2020-11-28:
Для этого есть ПРы, но спасибо

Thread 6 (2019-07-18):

Чередование режимов точки доступа и локального при включении

kesha4, 2019-07-18:
Планирую иногда брать лампу на дачу где нет вайфая, а каждый раз изменять прошивку лень. Поэтому добавил самый простой, как мне кажется, вариант переключения без доработки железа - рандомный выбор при включении)
Если включился не тот режим, нужно просто вытащить из розетки вставить снова)

```
// --------- ESP --------
int r = micros()%2; // рандомный выбор режима при включении
#define ESP_MODE r
```

Didiv, 2019-09-10:
Логичнее бы при включении с "нажатой" кнопкой переходить в режим AP. А если не нажата - работать в режиме клиента.

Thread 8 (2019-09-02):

Зависания при недоступности NTP сервера

immago, 2019-09-02:
**Проблема:** Если NTP сервер недоступен происходит зависание примерно каждые 3 секунды на 1 секунду. В моем случае это происходило из-за нестандартного gateway роутера.

**Причина:** т.к. в таком состоянии доступа в интернет нет, получить время невозможно. В `timeTick()` строчка `timeClient.update()` пытается получить время и блокирует поток на 1 секундный таймаут.

**Решение для нестандартного gateway :**
```
byte IP_GTW[] = {192, 168, 1, 10};  // gateway
...
WiFi.config(IPAddress(IP_STA[0], IP_STA[1], IP_STA[2], IP_STA[3]),
                IPAddress(IP_GTW[0], IP_GTW[1], IP_GTW[2], IP_GTW[3]),
                IPAddress(255, 255, 255, 0));
```
**Демонстрация проблемы:** https://youtu.be/V2hN8KUBEi0

Эта проблема может воспроизводится если ntp сервер будет недоступен по другим причинам (нет интернета например).
Предлагаю в `timeTick` делать синхронизацию не циклично, по готовности, а раз в час (например). Так же это уменьшит избыточное количество запросов.

_PS. Спасибо за проект. Внес бы корректировку сам, но не мой профиль, сложновато, да и "костыль" меня пока устраивает._

dymmer, 2019-11-07:
та же проблема. подскажите пожалста как узнать какой шлюз ставить? и в версии 1.4 я уже не вижу таких настроек. Где что проставить? Пишет что интернет есть, IP получает для NTP, но все равно время не считает и тормозит как и у вас.

immago, 2019-11-07:
@dymmer Если я правильно понял в новых версиях убрали ручное выставление ip и проблема должна исчезнуть.

Но на всякий случай шлюз можно узнать командой ipconfig /all с командной строке.
Еще можете попробовать альтернативные прошивки со страницы проекта. На прошивке от gunner47 такой проблемы точно нет.

dymmer, 2019-11-07:
спасибо за ответ. у меня с версией 1.5.1 приложение не работает. видел что там убрали, но приложуха ругается и вылетает. мне пока не понятно почему у меня в принципе NTP не получает...на работе работает, дома не хочет. gunner-а попробую еще, вроде ставил его уже, спасибо

andreu7530, 2021-03-25:
поменял сервер на "ru.pool.ntp.org"   все заработало

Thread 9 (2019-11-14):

Описание протолкала команд

zenderman, 2019-11-14:
Лампу можно подключить к умному дому. Подскажите описания протолкала http запросов  с переменными и значениями.

BDskii, 2019-12-17:
Уже сделали:
https://github.com/Whilser/GyverLamp

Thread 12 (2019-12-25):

CI pipeline для автоматической сборки прошивки

trapwalker, 2019-12-25:
Недавно на хабре проскочила [статья](https://habr.com/ru/post/479718/) как раз про автосборку средствами гитхаба бинарников под платформу данного проекта.

Это позволит получать прямо с гитхаба готовые бинарники сразу после релиза и не компилировать их у себя.

В [выше упомянутой статье](https://habr.com/ru/post/479718/) есть пример скрипта для настройки  CI. Мне ещё не все компоненты приехали из китая и не на чем попробовать, а-то бы я занялся этим вопросом и сделал бы пуллриквест. Так, собственно, и сделаю, если никто не сделает раньше.

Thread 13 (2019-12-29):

Не "корректная/реалистичная" работа огня

DisDis, 2019-12-29:
Огонь сменяется слишком дискретно, причина как мне кажется в том что скорость в текущей конфигурации влияет на FPS, а в идеальном варианте должна влиять на скорость изменения/интерполяции самого эффекта.(в текущем коде проценты меняются со скоростью 30 https://github.com/AlexGyver/GyverLamp/blob/master/firmware/GyverLamp_v1.5.5/effects.ino#L78 )
и сам таймер https://github.com/AlexGyver/GyverLamp/blob/master/firmware/GyverLamp_v1.5.5/effectTicker.ino#L5

я попробую поэксперементировать, но может есть сразу подводные камни или предложения куда копать?

DisDis, 2019-12-29:
@gunner47 может у вас есть идеи?

gunner47, 2019-12-29:
Если вы понимаете под "слишком дискретно" "слишком не плавно, ступенчато", тогда таймеры  не причём. Таймеры влияют на скорость, но не на плавность. Предположим, в прошивке есть другой ёмкий по времени код в цикле loop. Он выполняется дольше, чем заданное время между перерисовками "кадров" эффекта огня. Получается, каждый "кадр" будет отображаться матрицей дольше, визуально огонь станет медленнее. Но не ступенчатее. При условии, что тот другой код тратит одинаковое время на каждую свою итерацию. Что может негативно влиять на плавность? Скорее всего, pcnt, о которых вы написали выше (следующий "кадр" слишком далеко смещён относительно предыдущего). Либо инертность матрицы или глаз :) В последнее не верю.

DisDis, 2019-12-29:
@gunner47 я и топлю за то что бы плавность поднять. сейчас скорость влияет на таймер, но не на плавность.

XB1ades, 2023-01-08:
@AlexGyver @gunner47 Здравствуйте,что делать если при включении эффекта огня огонь работает по всей поверхности ленты?
может ли это происходить изза того что я просто намотал ленту на трубу?
найстройки размера стоят правильно

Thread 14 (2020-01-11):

Проблема компиляции v1.5 версия с MQTT от Whilser

ejik87, 2020-01-11:
При первой сборке лампы скомпилировал прошивку v1.4 MQTT всё работает, решил внести исправления в параметрах и обновление. Возникает ошибка компиляции, любые пути решения проверки версий библиотек и плат не увенчались успехом.
Не смог разобраться где корень проблемы.

mqtt:2:1: error: 'MQTTconfig' does not name a type

 MQTTconfig readMQTTConfig () {

 ^

C:\Temp\GyverLamp-master\firmware\GyverLamp_v1.5_MQTT\GyverLamp_v1.5_MQTT.ino: In function 'void setup()':

GyverLamp_v1.5_MQTT:399:42: error: 'readMQTTConfig' was not declared in this scope

   MQTTconfig MQTTConfig = readMQTTConfig();

Используем библиотеку FastLED-3.2.9 версии 3.2.9 из папки: C:\Program Files (x86)\Arduino\libraries\FastLED-3.2.9
Используем библиотеку ESP8266WiFi версии 1.0 из папки: C:\Users\EJ\AppData\Local\Arduino15\packages\esp8266\hardware\esp8266\2.5.2\libraries\ESP8266WiFi
Используем библиотеку DNSServer версии 1.1.1 из папки: C:\Users\EJ\AppData\Local\Arduino15\packages\esp8266\hardware\esp8266\2.5.2\libraries\DNSServer
Используем библиотеку ESP8266WebServer версии 1.0 из папки: C:\Users\EJ\AppData\Local\Arduino15\packages\esp8266\hardware\esp8266\2.5.2\libraries\ESP8266WebServer
Используем библиотеку ESP8266mDNS версии 1.2 из папки: C:\Users\EJ\AppData\Local\Arduino15\packages\esp8266\hardware\esp8266\2.5.2\libraries\ESP8266mDNS
Используем библиотеку ESP8266HTTPUpdateServer версии 1.0 из папки: C:\Users\EJ\AppData\Local\Arduino15\packages\esp8266\hardware\esp8266\2.5.2\libraries\ESP8266HTTPUpdateServer
Используем библиотеку WiFiManager версии 0.15.0-beta из папки: C:\Program Files (x86)\Arduino\libraries\WiFiManager
Используем библиотеку EEPROM версии 1.0 из папки: C:\Users\EJ\AppData\Local\Arduino15\packages\esp8266\hardware\esp8266\2.5.2\libraries\EEPROM
Используем библиотеку NTPClient версии 3.2.0 из папки: C:\Program Files (x86)\Arduino\libraries\NTPClient
Используем библиотеку GyverButton в папке: C:\Program Files (x86)\Arduino\libraries\GyverButton (legacy)
Используем библиотеку PubSubClient версии 2.7 из папки: C:\Program Files (x86)\Arduino\libraries\PubSubClient
Используем библиотеку ArduinoJson версии 6.11.3 из папки: C:\Program Files (x86)\Arduino\libraries\ArduinoJson
Используем библиотеку ArduinoOTA версии 1.0 из папки: C:\Users\EJ\AppData\Local\Arduino15\packages\esp8266\hardware\esp8266\2.5.2\libraries\ArduinoOTA
Используем библиотеку Timer в папке: C:\Program Files (x86)\Arduino\libraries\Timer (legacy)
exit status 1
'MQTTconfig' does not name a type

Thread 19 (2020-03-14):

Куда писать ишью для  gunner47? Есть проблема. (Это вопрос)

sapolio, 2020-03-14:
Я дичайше извиняюсь, что сюда пишу. Просто не понял как обратиться к  gunner47.
Бейте не сильно, отправьте в нужный форум, плиз.
Просто установил его прошивку, а там работает со старта только режим точки доступа.
В Вашей же прошивке, как сейчас помню, при первом обращении к WiFi платы можно было настроить подключение её к роутеру.
Я в файле констант у него нашёл следующее:
`#define ESP_MODE              (1U)                          // 0U - WiFi точка доступа, 1U - клиент WiFi (подключение к роутеру)
`
Ставил обе - 42.
 У меня плата с надписью "D1 MINI PRO". Пробовал выставлять другие esp - 42.

Forfeit76, 2020-04-14:
Попробуй тут:
https://community.alexgyver.ru/threads/wifi-lampa-budilnik.1406/

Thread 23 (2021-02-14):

Проблема с загрузкой обновленной прошивки под работу с Iphone

Luni3, 2021-02-14:
Доброй ночи. Просьба помочь в решение вопроса. Возникает проблема ссылаясь на файл #include "timer2Minim.h" появляется ошибка  о том что такой фаил найти он не может. При этом в репе вижу фаил с таким названием. Пробовал ради интереса удалять его, но в include  еще с одним файлом такая проблема. Просьба подсказать не обращался ли кто с подобной проблемой

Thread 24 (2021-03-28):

проблема настройки Wi-Fi подключения к роутеру

sor88, 2021-03-28:
модуль стартует только в режиме точки доступа. первый раз был запуск менеджера wi-fi%) после этого( пытался сбросить, или перепрошить заново) никаких эффектов, в wi-fi сети не появляется, вместо этого работает в режиме точки доступа на своем стандартном (указанном в прошивке) ip 192.168.4.1. Подскажите куда копать ?

sor88, 2021-03-28:
сборка без кнопки

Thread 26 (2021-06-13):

First LED of Matrix is flashing/flickering green

Puh73, 2021-06-13:
I have the problem, that the first LED of my 16x16 LED Matrix is flashing/flickering green. I already have googled this problem and found out that I am not the only one with this problem. In Internet I found many people who have problems with NodeMCU, ESP8266, Wemos D1, and other boards and WS2812 LED-Strips with flashing/flickering green first LED-Pixel and no one have solved this issue. I saw that you have added an resistor and diode on LED-Strip of GyverLamp2 but with no description why and I think the diode don’t is in the right direction. So I hope you can help or describe why you have done this and only on GyverLamp2 and not change the scheme of GyverLamp. Am I the only one with this flashing first LED-Pixel problem? Thank you in advance.

Patrick

camohob, 2022-11-25:
+1, i have the same problem. @Puh73 did you solve this problem?

Puh73, 2022-11-25:
> +1, i have the same problem. @Puh73 did you solve this problem?

Yes, the problem was caused by the ESP8266 Driver. You have to switch to an older driver in Arduino IDE than everything works fine.

gigby, 2022-12-03:
@Puh73 I have the same issue. I installed 3.0.2v of the ESP8266 driver for my mac m1 (suggested version 2.5.2 got error during compilation because coulndn't find python (and a magic with symlinks didn't help me)).
Which version did you use to fix this issue?

gigby, 2022-12-05:
The issue fixed via installing esp8266 v2.6.0. Now everything works stable.
First of all, I was trying to install fork from Gunner (86 in 1).
When I followed instructions from archive (installed esp v2.5.2 etc) I got issue with broken symlink and loosing wi-fi signal when you're changing effect from expanded list (esp_mode=1). Symlink to python was fixed but it was impossible to fix wi-fi issue.
PS: I have mac os Ventura 13.0.1, python v3.11.0 and latest version of Gunner47 firmware. Probably current project (original) doesn't have wi-fi issue at all.

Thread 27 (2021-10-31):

Не запоминает состояние при выключении

Spirituss, 2021-10-31:
При отключении/потере лампы в сети/рестарте - состояние лампы не запоминается. Часто самопроизвольно включается при этом.

Spirituss, 2022-01-10:
Есть ли новости? Когда ждать обновление?

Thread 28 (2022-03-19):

Перевесьте led_pin

whoim2, 2022-03-19:
По схеме на 8266 он висит на io2, это вызывает бутлуп при старте, с матрицей 16х16 точно. Я повесил на d1 (wemos d1 mini) и указал 5u пин, работает четко.

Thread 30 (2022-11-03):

Не прямоугольная матрица

maxcoff, 2022-11-03:
Возможно ли применить не прямоугольную матрицу. Например в виде треугольника. Идея сделать подсветку плоской проекции елочки.
Посмотрел что в эффектах везде указаны переменные HEIGHT и WIDTH указывающие на ширину и высоту, но как в данном случае указать ширину и высоту прямоугольного треугольника не понимаю. Как например, указать что в первом столбце 1 светодиод, во втором - 3, в третьем 5 и т.д. до 25, а потом по убывающей?

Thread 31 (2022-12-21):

451-Add OS Kazexpoaudit

junecat, 2022-12-21:
Обращение: Прошу в Движок торговли добавить ОС ТОО "КАЗЭКСПОАУДИТ" (KZ.O.02.0361)

Обратите внимание! ОС, а не ИЛ!

junecat, 2022-12-21:
Прошу прощения, не в тот репо написал!

Closed 2022-12-21.

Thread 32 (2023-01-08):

Что делать если при включении эффекта огня огонь работает по всей поверхности ленты?

XB1ades, 2023-01-08:
Что делать если при включении эффекта огня огонь работает по всей поверхности ленты?
может ли это происходить изза того что я просто намотал ленту на трубу а не сделал матрицу?

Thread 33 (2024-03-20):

А где версия 1.5 или 2.1 ???

khusamov, 2024-03-20:
Добрый день!
Нашел ваш проект на странице https://alexgyver.ru/gyverlamp/
Там упоминаются версии 1.5 и 2.1
А в репозитории я вижу только 1.4

Вопрос, а где более свежие версии хранятся?

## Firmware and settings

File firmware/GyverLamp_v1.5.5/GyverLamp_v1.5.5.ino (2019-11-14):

/*
  Скетч к проекту "Многофункциональный RGB светильник"
  Страница проекта (схемы, описания): https://alexgyver.ru/GyverLamp/
  Исходники на GitHub: https://github.com/AlexGyver/GyverLamp/
  Нравится, как написан код? Поддержи автора! https://alexgyver.ru/support_alex/
  Автор: AlexGyver, AlexGyver Technologies, 2019
  https://AlexGyver.ru/
*/

/*
  Версия 1.5.1
  - Оптимизировано обращение к серверу времени (нет подвисаний при отсутствии интернета)
  - Оптимизация под пины NodeMCU

  Версия 1.5.2
  - Исправлен незначительный баг с таймером
  - Исправлено падение по WDT при выводе IP
  - Исправлен баг с переназначением времени будильника
  - Исправлено переключение с первого на последний режимы
  - Приложение автоматически получает настройки с кнопки
  - Бегущая строка с текущим временем во время рассвета

  Версия 1.5.3
  - Увеличена плавность рассвета
  - Поправлен баг с отображением времени рассвета

  Версия 1.5.4
  - Поправлены глюки во время рассвета
  
  Версия 1.5.5
  - Поправлено невыключение света во время рассвета

*/

// Ссылка для менеджера плат:
// http://arduino.esp8266.com/stable/package_esp8266com_index.json

// Для WEMOS выбираем плату LOLIN(WEMOS) D1 R2 & mini
// Для NodeMCU выбираем NodeMCU 1.0 (ESP-12E Module)

// ============= НАСТРОЙКИ =============
// -------- КНОПКА -------
#define USE_BUTTON 1    // 1 - использовать кнопку, 0 - нет

// -------- ВРЕМЯ -------
#define GMT 3              // смещение (москва 3)
#define NTP_ADDRESS  "europe.pool.ntp.org"    // сервер времени

// -------- РАССВЕТ -------
#define DAWN_BRIGHT 200       // макс. яркость рассвета
#define DAWN_TIMEOUT 1        // сколько рассвет светит после времени будильника, минут

// ---------- МАТРИЦА ---------
#define BRIGHTNESS 40         // стандартная маскимальная яркость (0-255)
#define CURRENT_LIMIT 2000    // лимит по току в миллиамперах, автоматически управляет яркостью (пожалей свой блок питания!) 0 - выключить лимит

#define WIDTH 16              // ширина матрицы
#define HEIGHT 16             // высота матрицы

#define COLOR_ORDER GRB       // порядок цветов на ленте. Если цвет отображается некорректно - меняйте. Начать можно с RGB

#define MATRIX_TYPE 0         // тип матрицы: 0 - зигзаг, 1 - параллельная
#define CONNECTION_ANGLE 0    // угол подключения: 0 - левый нижний, 1 - левый верхний, 2 - правый верхний, 3 - правый нижний
#define STRIP_DIRECTION 0     // направление ленты из угла: 0 - вправо, 1 - вверх, 2 - влево, 3 - вниз
// при неправильной настройке матрицы вы получите предупреждение "Wrong matrix parameters! Set to default"
// шпаргалка по настройке матрицы здесь! https://alexgyver.ru/matrix_guide/

// --------- ESP --------
#define ESP_MODE 1
// 0 - точка доступа
// 1 - локальный
byte IP_AP[] = {192, 168, 4, 66};   // статический IP точки доступа (менять только последнюю цифру)

// ----- AP (точка доступа) -------
#define AP_SSID "GyverLamp"
#define AP_PASS "12345678"
#define AP_PORT 8888

// -------- Менеджер WiFi ---------
#define AC_SSID "AutoConnectAP"
#define AC_PASS "12345678"

// ============= ДЛЯ РАЗРАБОТЧИКОВ =============
#define LED_PIN D4             // пин ленты
#define BTN_PIN D2
#define MODE_AMOUNT 18

#define NUM_LEDS WIDTH * HEIGHT
#define SEGMENTS 1            // диодов в одном "пикселе" (для создания матрицы из кусков ленты)
// ---------------- БИБЛИОТЕКИ -----------------
#define FASTLED_INTERRUPT_RETRY_COUNT 0
#define FASTLED_ALLOW_INTERRUPTS 0
#define FASTLED_ESP8266_RAW_PIN_ORDER
#define NTP_INTERVAL 60 * 1000    // обновление (1 минута)

#include "timer2Minim.h"
#include <FastLED.h>
#include <ESP8266WiFi.h>
#include <DNSServer.h>
#include <ESP8266WebServer.h>
#include <WiFiManager.h>
#include <WiFiUdp.h>
#include <EEPROM.h>
#include <NTPClient.h>
#include <GyverButton.h>
#include "fonts.h"

// ------------------- ТИПЫ --------------------
CRGB leds[NUM_LEDS];
WiFiServer server(80);
WiFiUDP Udp;
WiFiUDP ntpUDP;
NTPClient timeClient(ntpUDP, NTP_ADDRESS, GMT * 3600, NTP_INTERVAL);
timerMinim timeTimer(1000);
timerMinim timeStrTimer(120);
GButton touch(BTN_PIN, LOW_PULL, NORM_OPEN);

// ----------------- ПЕРЕМЕННЫЕ ------------------
const char* autoConnectSSID = AC_SSID;
const char* autoConnectPass = AC_PASS;
const char AP_NameChar[] = AP_SSID;
const char WiFiPassword[] = AP_PASS;
unsigned int localPort = AP_PORT;
char packetBuffer[UDP_TX_PACKET_MAX_SIZE + 1]; //buffer to hold incoming packet
String inputBuffer;
static const byte maxDim = max(WIDTH, HEIGHT);
struct {
  byte brightness = 50;
  byte speed = 30;
  byte scale = 40;
} modes[MODE_AMOUNT];

struct {
  boolean state = false;
  int time = 0;
} alarm[7];

const byte dawnOffsets[] = {5, 10, 15, 20, 25, 30, 40, 50, 60};
byte dawnMode;
boolean dawnFlag = false;
float thisTime;
boolean manualOff = false;
boolean sendSettings_flag = false;

int8_t currentMode = 0;
boolean loadingFlag = true;
boolean ONflag = true;
uint32_t eepromTimer;
boolean settChanged = false;
// Конфетти, Огонь, Радуга верт., Радуга гориз., Смена цвета,
// Безумие 3D, Облака 3D, Лава 3D, Плазма 3D, Радуга 3D,
// Павлин 3D, Зебра 3D, Лес 3D, Океан 3D,

unsigned char matrixValue[8][16];
String lampIP = "";
byte hrs, mins, secs;
byte days;
String timeStr = "00:00";

void setup() {
  ESP.wdtDisable();
  //ESP.wdtEnable(WDTO_8S);

  // ЛЕНТА
  FastLED.addLeds<WS2812B, LED_PIN, COLOR_ORDER>(leds, NUM_LEDS)/*.setCorrection( TypicalLEDStrip )*/;
  FastLED.setBrightness(BRIGHTNESS);
  if (CURRENT_LIMIT > 0) FastLED.setMaxPowerInVoltsAndMilliamps(5, CURRENT_LIMIT);
  FastLED.show();

  touch.setStepTimeout(100);
  touch.setClickTimeout(500);

  Serial.begin(115200);
  Serial.println();
  delay(1000);

  // WI-FI
  if (ESP_MODE == 0) {    // режим точки доступа
    WiFi.softAPConfig(IPAddress(IP_AP[0], IP_AP[1], IP_AP[2], IP_AP[3]),
                      IPAddress(192, 168, 4, 1),
                      IPAddress(255, 255, 255, 0));

    WiFi.softAP(AP_NameChar, WiFiPassword);
    IPAddress myIP = WiFi.softAPIP();
    Serial.print("Access point Mode");
    Serial.print("AP IP address: ");
    Serial.println(myIP);

    server.begin();
  } else {                // подключаемся к роутеру
    Serial.print("WiFi manager");
    WiFiManager wifiManager;
    wifiManager.setDebugOutput(false);

#if (USE_BUTTON == 1)
    if (digitalRead(BTN_PIN)) wifiManager.resetSettings();
#endif

    wifiManager.autoConnect(autoConnectSSID, autoConnectPass);
    /*WiFi.config(IPAddress(IP_STA[0], IP_STA[1], IP_STA[2], IP_STA[3]),
                IPAddress(192, 168, 1, 1),
                IPAddress(255, 255, 255, 0));*/
    Serial.print("Connected! IP address: ");
    Serial.println(WiFi.localIP());
    lampIP = WiFi.localIP().toString();
  }
  Serial.printf("UDP server on port %d\n", localPort);
  Udp.begin(localPort);

  // EEPROM
  EEPROM.begin(202);
  delay(50);
  if (EEPROM.read(198) != 20) {   // первый запуск
    EEPROM.write(198, 20);
    EEPROM.commit();

    for (byte i = 0; i < MODE_AMOUNT; i++) {
      EEPROM.put(3 * i + 40, modes[i]);
      EEPROM.commit();
    }
    for (byte i = 0; i < 7; i++) {
      EEPROM.write(5 * i, alarm[i].state);   // рассвет
      eeWriteInt(5 * i + 1, alarm[i].time);
      EEPROM.commit();
    }
    EEPROM.write(199, 0);   // рассвет
    EEPROM.write(200, 0);   // режим
    EEPROM.commit();
  }
  for (byte i = 0; i < MODE_AMOUNT; i++) {
    EEPROM.get(3 * i + 40, modes[i]);
  }
  for (byte i = 0; i < 7; i++) {
    alarm[i].state = EEPROM.read(5 * i);
    alarm[i].time = eeGetInt(5 * i + 1);
  }
  dawnMode = EEPROM.read(199);
  currentMode = (int8_t)EEPROM.read(200);

  // отправляем настройки
  sendSettings();

  timeClient.begin();
  memset(matrixValue, 0, sizeof(matrixValue));

  randomSeed(micros());

  // получаем время
  byte count = 0;
  while (count < 5) {
    if (timeClient.update()) {
      hrs = timeClient.getHours();
      mins = timeClient.getMinutes();
      secs = timeClient.getSeconds();
      days = timeClient.getDay();
      break;
    }
    count++;
    delay(500);
  }
  updTime();
}

void loop() {
  parseUDP();
  effectsTick();
  eepromTick();
  timeTick();
#if (USE_BUTTON == 1)
  buttonTick();
#endif
  ESP.wdtFeed();   // пнуть собаку
  yield();  // ещё раз пнуть собаку
}

void eeWriteInt(int pos, int val) {
  byte* p = (byte*) &val;
  EEPROM.write(pos, *p);
  EEPROM.write(pos + 1, *(p + 1));
  EEPROM.write(pos + 2, *(p + 2));
  EEPROM.write(pos + 3, *(p + 3));
  EEPROM.commit();
}

int eeGetInt(int pos) {
  int val;
  byte* p = (byte*) &val;
  *p        = EEPROM.read(pos);
  *(p + 1)  = EEPROM.read(pos + 1);
  *(p + 2)  = EEPROM.read(pos + 2);
  *(p + 3)  = EEPROM.read(pos + 3);
  return val;
}

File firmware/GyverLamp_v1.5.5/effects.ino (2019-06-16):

// ================================= ЭФФЕКТЫ ====================================

// --------------------------------- конфетти ------------------------------------
void sparklesRoutine() {
  for (byte i = 0; i < modes[0].scale; i++) {
    byte x = random(0, WIDTH);
    byte y = random(0, HEIGHT);
    if (getPixColorXY(x, y) == 0)
      leds[getPixelNumber(x, y)] = CHSV(random(0, 255), 255, 255);
  }
  fader(70);
}

// функция плавного угасания цвета для всех пикселей
void fader(byte step) {
  for (byte i = 0; i < WIDTH; i++) {
    for (byte j = 0; j < HEIGHT; j++) {
      fadePixel(i, j, step);
    }
  }
}
void fadePixel(byte i, byte j, byte step) {     // новый фейдер
  int pixelNum = getPixelNumber(i, j);
  if (getPixColor(pixelNum) == 0) return;

  if (leds[pixelNum].r >= 30 ||
      leds[pixelNum].g >= 30 ||
      leds[pixelNum].b >= 30) {
    leds[pixelNum].fadeToBlackBy(step);
  } else {
    leds[pixelNum] = 0;
  }
}

// -------------------------------------- огонь ---------------------------------------------
// эффект "огонь"
#define SPARKLES 1        // вылетающие угольки вкл выкл
unsigned char line[WIDTH];
int pcnt = 0;

//these values are substracetd from the generated values to give a shape to the animation
const unsigned char valueMask[8][16] PROGMEM = {
  {32 , 0  , 0  , 0  , 0  , 0  , 0  , 32 , 32 , 0  , 0  , 0  , 0  , 0  , 0  , 32 },
  {64 , 0  , 0  , 0  , 0  , 0  , 0  , 64 , 64 , 0  , 0  , 0  , 0  , 0  , 0  , 64 },
  {96 , 32 , 0  , 0  , 0  , 0  , 32 , 96 , 96 , 32 , 0  , 0  , 0  , 0  , 32 , 96 },
  {128, 64 , 32 , 0  , 0  , 32 , 64 , 128, 128, 64 , 32 , 0  , 0  , 32 , 64 , 128},
  {160, 96 , 64 , 32 , 32 , 64 , 96 , 160, 160, 96 , 64 , 32 , 32 , 64 , 96 , 160},
  {192, 128, 96 , 64 , 64 , 96 , 128, 192, 192, 128, 96 , 64 , 64 , 96 , 128, 192},
  {255, 160, 128, 96 , 96 , 128, 160, 255, 255, 160, 128, 96 , 96 , 128, 160, 255},
  {255, 192, 160, 128, 128, 160, 192, 255, 255, 192, 160, 128, 128, 160, 192, 255}
};

//these are the hues for the fire,
//should be between 0 (red) to about 25 (yellow)
const unsigned char hueMask[8][16] PROGMEM = {
  {1 , 11, 19, 25, 25, 22, 11, 1 , 1 , 11, 19, 25, 25, 22, 11, 1 },
  {1 , 8 , 13, 19, 25, 19, 8 , 1 , 1 , 8 , 13, 19, 25, 19, 8 , 1 },
  {1 , 8 , 13, 16, 19, 16, 8 , 1 , 1 , 8 , 13, 16, 19, 16, 8 , 1 },
  {1 , 5 , 11, 13, 13, 13, 5 , 1 , 1 , 5 , 11, 13, 13, 13, 5 , 1 },
  {1 , 5 , 11, 11, 11, 11, 5 , 1 , 1 , 5 , 11, 11, 11, 11, 5 , 1 },
  {0 , 1 , 5 , 8 , 8 , 5 , 1 , 0 , 0 , 1 , 5 , 8 , 8 , 5 , 1 , 0 },
  {0 , 0 , 1 , 5 , 5 , 1 , 0 , 0 , 0 , 0 , 1 , 5 , 5 , 1 , 0 , 0 },
  {0 , 0 , 0 , 1 , 1 , 0 , 0 , 0 , 0 , 0 , 0 , 1 , 1 , 0 , 0 , 0 }
};

void fireRoutine() {
  if (loadingFlag) {
    loadingFlag = false;
    //FastLED.clear();
    generateLine();
  }
  if (pcnt >= 100) {
    shiftUp();
    generateLine();
    pcnt = 0;
  }
  drawFrame(pcnt);
  pcnt += 30;
}

// Randomly generate the next line (matrix row)

void generateLine() {
  for (uint8_t x = 0; x < WIDTH; x++) {
    line[x] = random(64, 255);
  }
}

void shiftUp() {
  for (uint8_t y = HEIGHT - 1; y > 0; y--) {
    for (uint8_t x = 0; x < WIDTH; x++) {
      uint8_t newX = x;
      if (x > 15) newX = x - 15;
      if (y > 7) continue;
      matrixValue[y][newX] = matrixValue[y - 1][newX];
    }
  }

  for (uint8_t x = 0; x < WIDTH; x++) {
    uint8_t newX = x;
    if (x > 15) newX = x - 15;
    matrixValue[0][newX] = line[newX];
  }
}

// draw a frame, interpolating between 2 "key frames"
// @param pcnt percentage of interpolation

void drawFrame(int pcnt) {
  int nextv;

  //each row interpolates with the one before it
  for (unsigned char y = HEIGHT - 1; y > 0; y--) {
    for (unsigned char x = 0; x < WIDTH; x++) {
      uint8_t newX = x;
      if (x > 15) newX = x - 15;
      if (y < 8) {
        nextv =
          (((100.0 - pcnt) * matrixValue[y][newX]
            + pcnt * matrixValue[y - 1][newX]) / 100.0)
          - pgm_read_byte(&(valueMask[y][newX]));

        CRGB color = CHSV(
                       modes[1].scale * 2.5 + pgm_read_byte(&(hueMask[y][newX])), // H
                       255, // S
                       (uint8_t)max(0, nextv) // V
                     );

        leds[getPixelNumber(x, y)] = color;
      } else if (y == 8 && SPARKLES) {
        if (random(0, 20) == 0 && getPixColorXY(x, y - 1) != 0) drawPixelXY(x, y, getPixColorXY(x, y - 1));
        else drawPixelXY(x, y, 0);
      } else if (SPARKLES) {

        // старая версия для яркости
        if (getPixColorXY(x, y - 1) > 0)
          drawPixelXY(x, y, getPixColorXY(x, y - 1));
        else drawPixelXY(x, y, 0);

      }
    }
  }

  //first row interpolates with the "next" line
  for (unsigned char x = 0; x < WIDTH; x++) {
    uint8_t newX = x;
    if (x > 15) newX = x - 15;
    CRGB color = CHSV(
                   modes[1].scale * 2.5 + pgm_read_byte(&(hueMask[0][newX])), // H
                   255,           // S
                   (uint8_t)(((100.0 - pcnt) * matrixValue[0][newX] + pcnt * line[newX]) / 100.0) // V
                 );
    leds[getPixelNumber(newX, 0)] = color;
  }
}

byte hue;
// ---------------------------------------- радуга ------------------------------------------
void rainbowVertical() {
  hue += 2;
  for (byte j = 0; j < HEIGHT; j++) {
    CHSV thisColor = CHSV((byte)(hue + j * modes[2].scale), 255, 255);
    for (byte i = 0; i < WIDTH; i++)
      drawPixelXY(i, j, thisColor);
  }
}
void rainbowHorizontal() {
  hue += 2;
  for (byte i = 0; i < WIDTH; i++) {
    CHSV thisColor = CHSV((byte)(hue + i * modes[3].scale), 255, 255);
    for (byte j = 0; j < HEIGHT; j++)
      drawPixelXY(i, j, thisColor);   //leds[getPixelNumber(i, j)] = thisColor;
  }
}

// ---------------------------------------- ЦВЕТА ------------------------------------------
void colorsRoutine() {
  hue += modes[4].scale;
  for (int i = 0; i < NUM_LEDS; i++) {
    leds[i] = CHSV(hue, 255, 255);
  }
}

// --------------------------------- ЦВЕТ ------------------------------------
void colorRoutine() {
  for (int i = 0; i < NUM_LEDS; i++) {
    leds[i] = CHSV(modes[14].scale * 2.5, 255, 255);
  }
}

// ------------------------------ снегопад 2.0 --------------------------------
void snowRoutine() {
  // сдвигаем всё вниз
  for (byte x = 0; x < WIDTH; x++) {
    for (byte y = 0; y < HEIGHT - 1; y++) {
      drawPixelXY(x, y, getPixColorXY(x, y + 1));
    }
  }

  for (byte x = 0; x < WIDTH; x++) {
    // заполняем случайно верхнюю строку
    // а также не даём двум блокам по вертикали вместе быть
    if (getPixColorXY(x, HEIGHT - 2) == 0 && (random(0, modes[15].scale) == 0))
      drawPixelXY(x, HEIGHT - 1, 0xE0FFFF - 0x101010 * random(0, 4));
    else
      drawPixelXY(x, HEIGHT - 1, 0x000000);
  }
}
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
